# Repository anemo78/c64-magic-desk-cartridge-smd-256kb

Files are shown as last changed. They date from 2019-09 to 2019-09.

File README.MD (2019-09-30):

# C64 Magic Desk Cartridge 256kb (SMD version)

This version of the Magic Desk compatible cartridge uses mainly SMD components and supports 28* and 32** pin (E)EPROM and FLASH memory chips **up to 256kB**. The type of memory chip is configured with a solder bridge on the back of the PCB.

The Magic Desk cartridge was originally created by Commodore. Marko Šolajić and Žarko Živanov then utilized the same memory bank switching technique and created the [Magic Desk Cart Generator 2.0](https://csdb.dk/release/?id=132937). ***Please note that the MDCG is now available in version 3.0 and supports up to 1MB memory with slightly different hardware.***

***28-pin:**
M27512, M27C512, AM27C512, W27C512, W27E512, 27SF512, 39SF512 and more

****32-pin:**
M27C2001, M27C1001, NM27C020, NM27C010, AT29C020, AT29C010, 39SF010A, 39SF020A and more

**The MDCG project is available under GNU GENERAL PUBLIC LICENSE.**

## Bill of materials (BOM)

| Name | Component |
|--|--|
| U1 | DIP 28/32 (E)EPROM/FLASH memory (see above) |
| U2 | 74LS02D SO-14 (or HCT) |
| U3 | 74LS174D SO-16 (or HCT) |
| C1-C2 | 100nF 0805 size capacitor |
| R1 | 10k 0805 size resistor |
| S1 | TACT switch (SCHURTER 1301.9303 for instance) |

## PCB Images

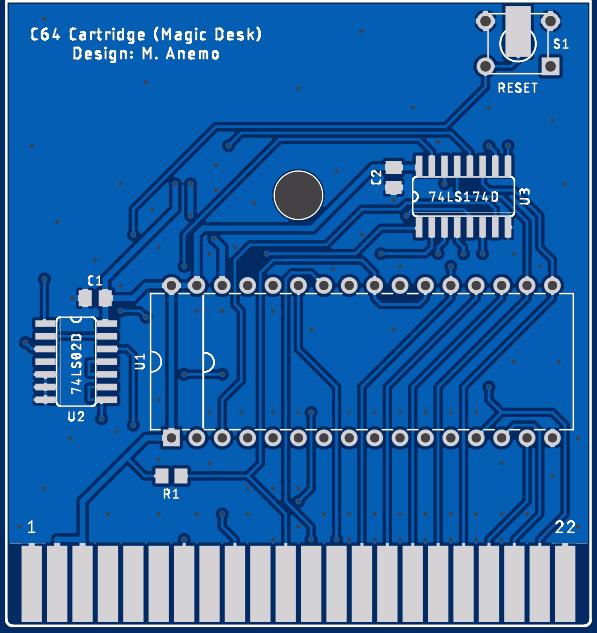
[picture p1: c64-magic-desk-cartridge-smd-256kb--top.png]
PCB top


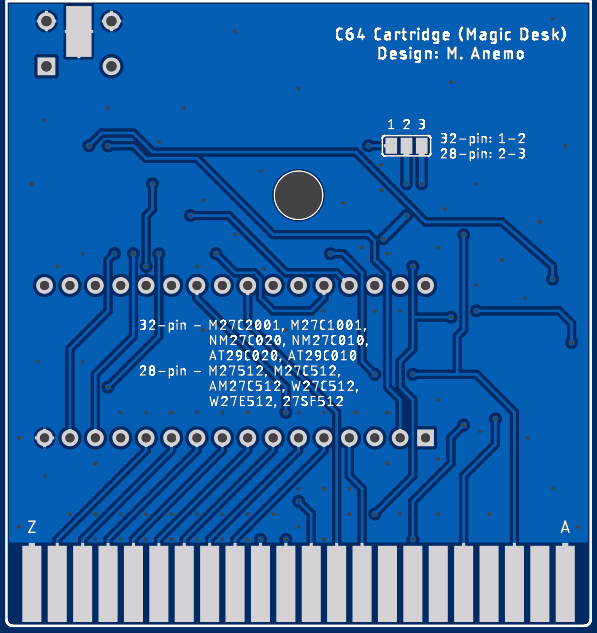
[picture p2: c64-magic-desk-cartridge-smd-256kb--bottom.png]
PCB bottom


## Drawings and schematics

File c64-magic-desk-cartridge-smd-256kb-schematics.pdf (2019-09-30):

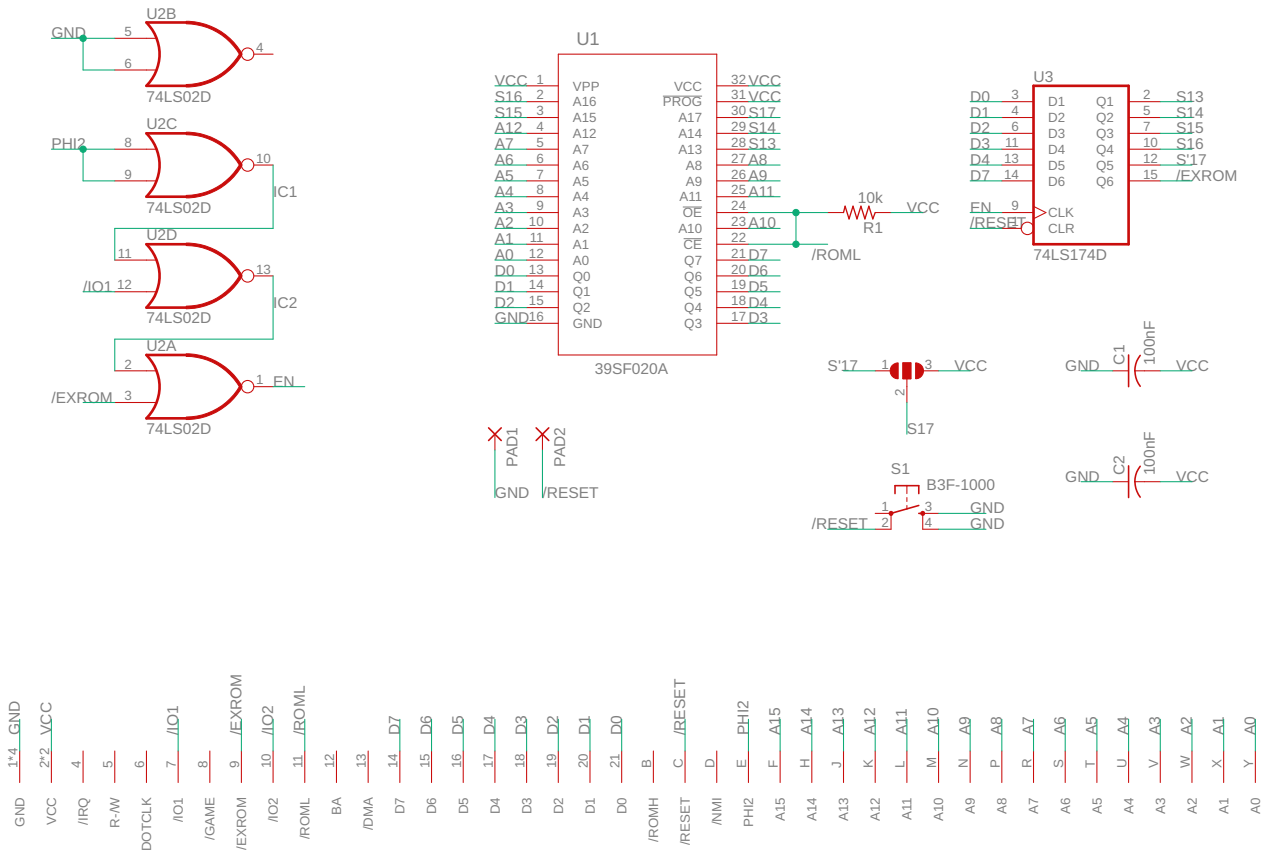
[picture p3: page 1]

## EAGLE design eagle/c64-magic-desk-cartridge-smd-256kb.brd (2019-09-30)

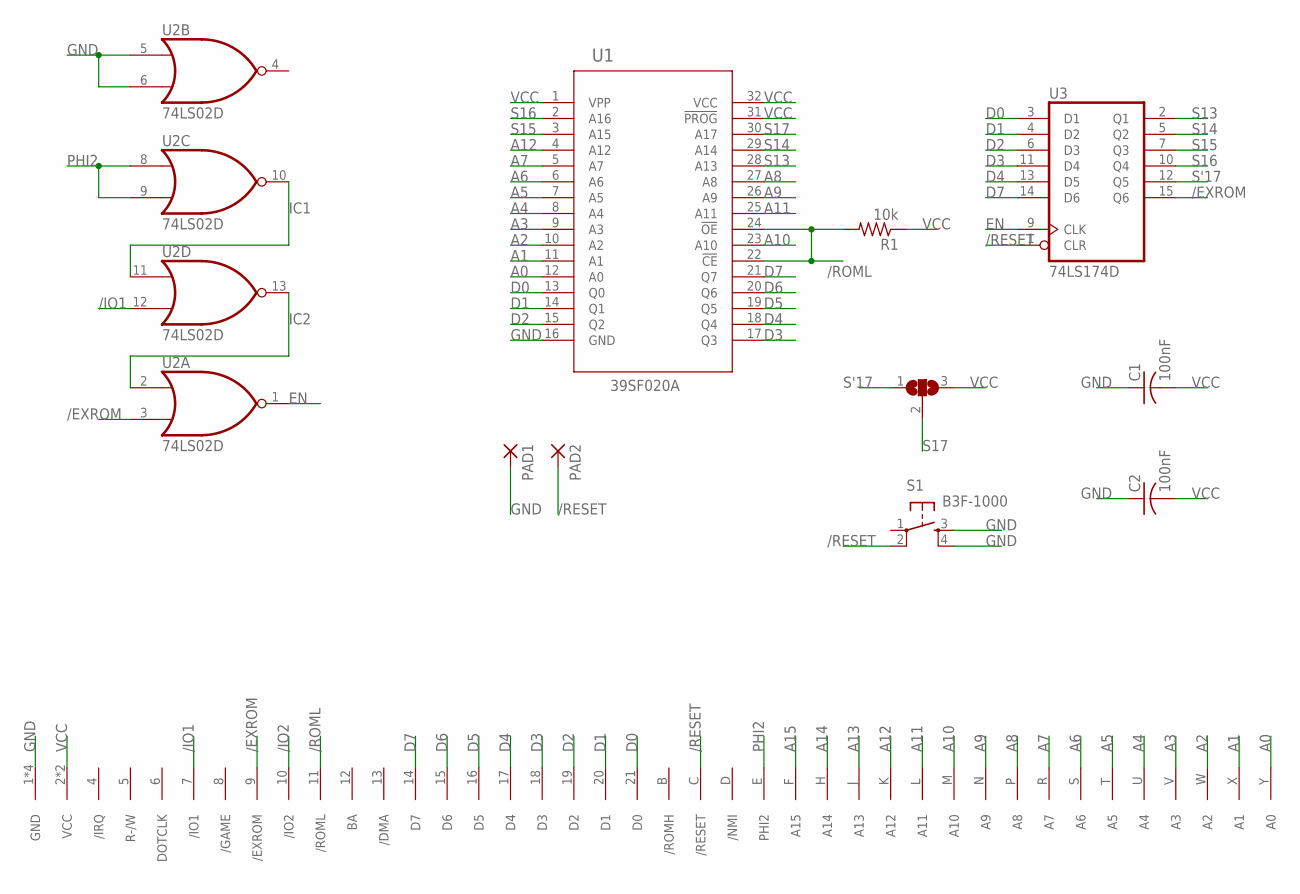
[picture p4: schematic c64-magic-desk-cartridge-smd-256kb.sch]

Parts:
C1, C2: 100nF; C0805K
PAD1, PAD2: SMD2.54-5.08; SMD2,54-5,08
R1: 10k; R0805
S1: B3F-1000; B3F-10XX
SJ1: SJ2W; SJ_2
U1: M27C2001DIP32-LOWERED; DIP32
U2: 74LS02D; SO14
U3: 74LS174D; SO16
U$1: C64-EXPANSION-PORT; EXPANSION_PORT

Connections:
/EXROM: U2.3 (I1), U3.15 (Q6), U$1.9 (/EXROM)
/IO1: U2.12 (I1), U$1.7 (/IO1)
/IO2: U$1.10 (/IO2)
/RESET: PAD2.P$1, S1.2 (P1), U3.1 (CLR), U$1.C (/RESET)
/ROML: R1.2, U1.22 (!CE), U1.24 (!OE), U$1.11 (/ROML)
A0: U1.12 (A0), U$1.Y (A0)
A1: U1.11 (A1), U$1.X (A1)
A2: U1.10 (A2), U$1.W (A2)
A3: U1.9 (A3), U$1.V (A3)
A4: U1.8 (A4), U$1.U (A4)
A5: U1.7 (A5), U$1.T (A5)
A6: U1.6 (A6), U$1.S (A6)
A7: U1.5 (A7), U$1.R (A7)
A8: U1.27 (A8), U$1.P (A8)
A9: U1.26 (A9), U$1.N (A9)
A10: U1.23 (A10), U$1.M (A10)
A11: U1.25 (A11), U$1.L (A11)
A12: U1.4 (A12), U$1.K (A12)
A13: U$1.J (A13)
A14: U$1.H (A14)
A15: U$1.F (A15)
D0: U1.13 (Q0), U3.3 (D1), U$1.21 (D0)
D1: U1.14 (Q1), U3.4 (D2), U$1.20 (D1)
D2: U1.15 (Q2), U3.6 (D3), U$1.19 (D2)
D3: U1.17 (Q3), U3.11 (D4), U$1.18 (D3)
D4: U1.18 (Q4), U3.13 (D5), U$1.17 (D4)
D5: U1.19 (Q5), U$1.16 (D5)
D6: U1.20 (Q6), U$1.15 (D6)
D7: U1.21 (Q7), U3.14 (D6), U$1.14 (D7)
EN: U2.1 (O), U3.9 (CLK)
GND: C1.1, C2.1, PAD1.P$1, S1.3 (S), S1.4 (S1), U1.16 (GND), U2.5 (I0), U2.6 (I1), U2.7 (GND), U3.8 (GND), U$1.1 (GND), U$1.22 (GND), U$1.A (GND), U$1.Z (GND)
IC1: U2.10 (O), U2.11 (I0)
IC2: U2.2 (I0), U2.13 (O)
PHI2: U2.8 (I0), U2.9 (I1), U$1.E (PHI2)
S13: U1.28 (A13), U3.2 (Q1)
S14: U1.29 (A14), U3.5 (Q2)
S15: U1.3 (A15), U3.7 (Q3)
S16: U1.2 (A16), U3.10 (Q4)
S17: SJ1.2, U1.30 (A17)
S'17: SJ1.1, U3.12 (Q5)
VCC: C1.2, C2.2, R1.1, SJ1.3, U1.1 (VPP), U1.31 (!PROG), U1.32 (VCC), U2.14 (VCC), U3.16 (VCC), U$1.2 (VCC), U$1.3 (VCC)

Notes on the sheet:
39SF020A

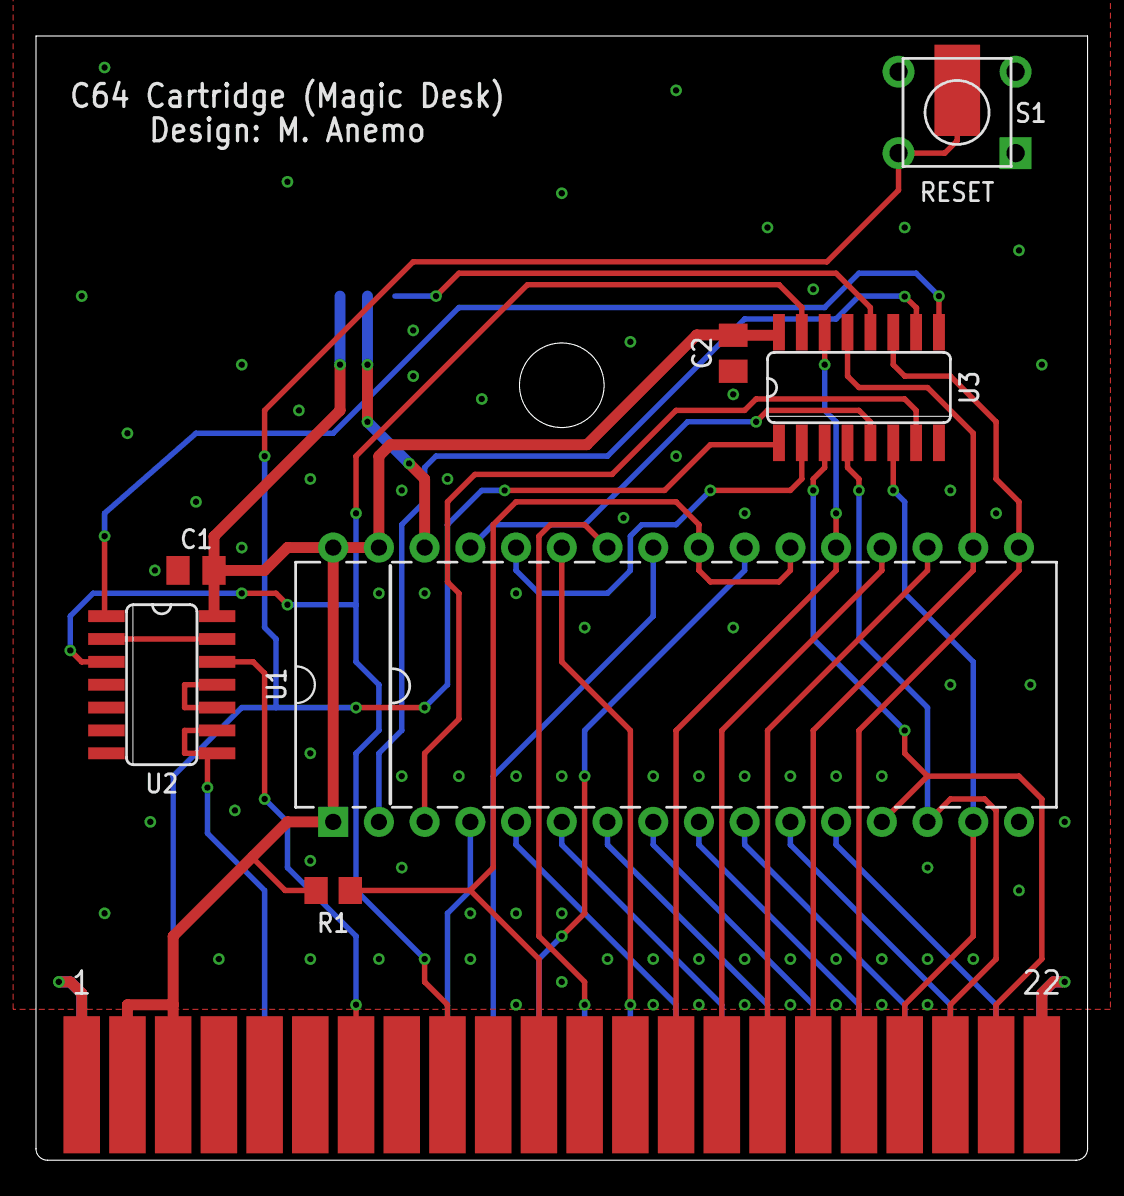
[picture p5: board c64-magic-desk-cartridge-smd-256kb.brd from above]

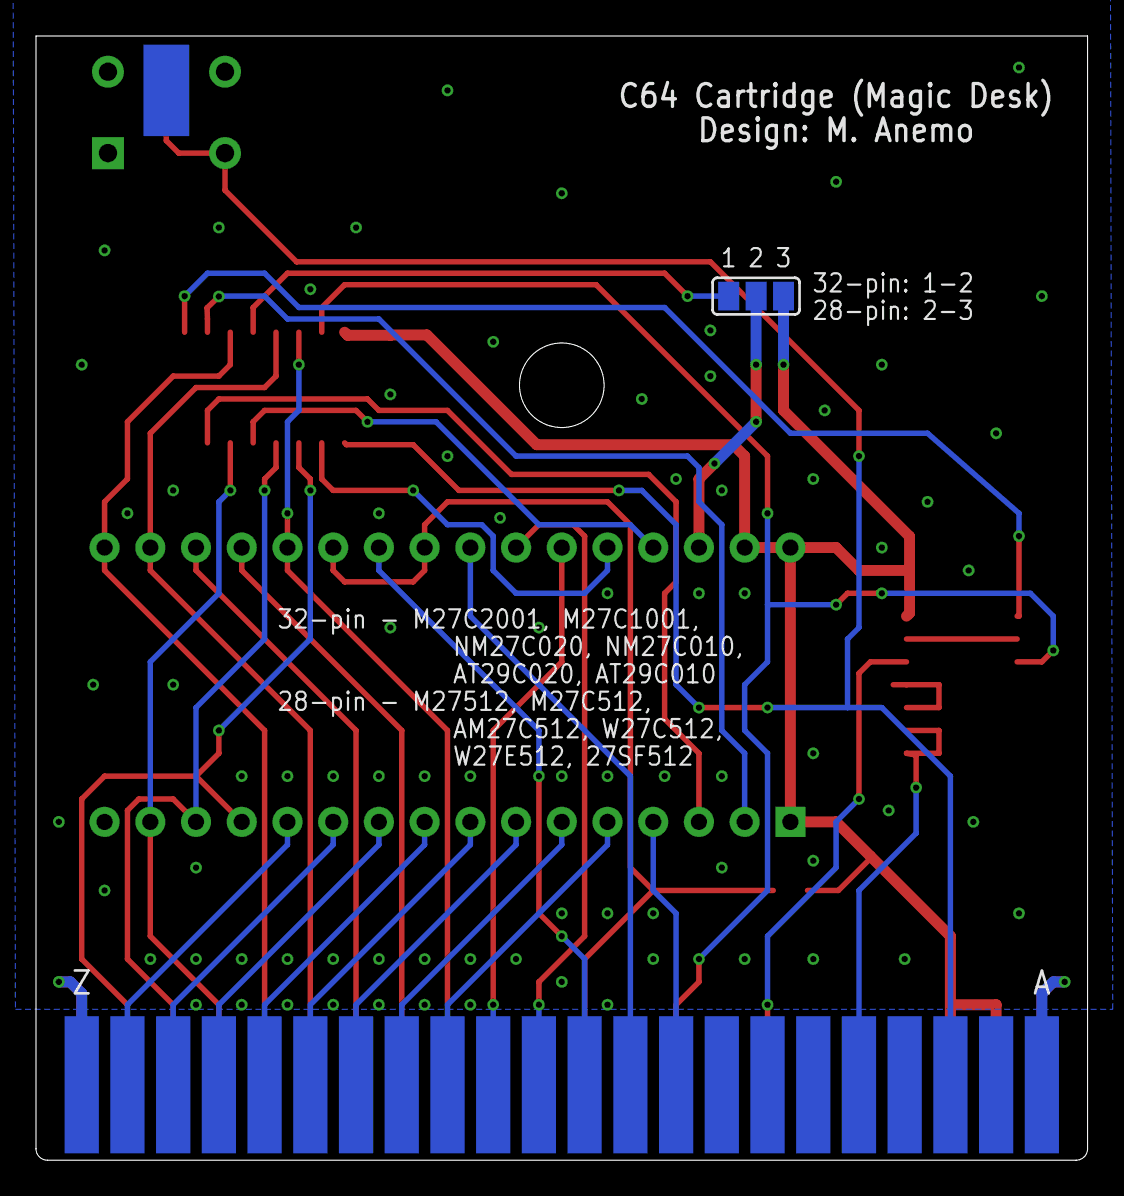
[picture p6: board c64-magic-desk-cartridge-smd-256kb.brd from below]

Board: 2 copper layers, 58.4 x 62.5 mm, 11 parts (2 on the bottom side), 37 nets.

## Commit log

2019-09-30 added pcb images
2019-09-30 moved eagle files to own folder
    [c64-magic-desk-cartridge-smd-256kb.brd, c64-magic-desk-cartridge-smd-256kb.sch]
2019-09-30 updated board text
    [c64-magic-desk-cartridge-smd-256kb.brd, c64-magic-desk-cartridge-smd-256kb.sch]
